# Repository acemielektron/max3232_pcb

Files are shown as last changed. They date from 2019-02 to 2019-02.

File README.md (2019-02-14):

# max3232_pcb
diy single sided pcb for max3232 RS232 to TTL serial

After cheap max3232 pcb was broken i have placed components with the addtion of 3.3k resistors on rs232 inputs on a diy pcb.

Why 3.3k resistors? because these cheap max3232 clones cause crosstalk while connected to a PC RS232 port. 
This was en effective solution. And with the new pcb i added rts and cts.

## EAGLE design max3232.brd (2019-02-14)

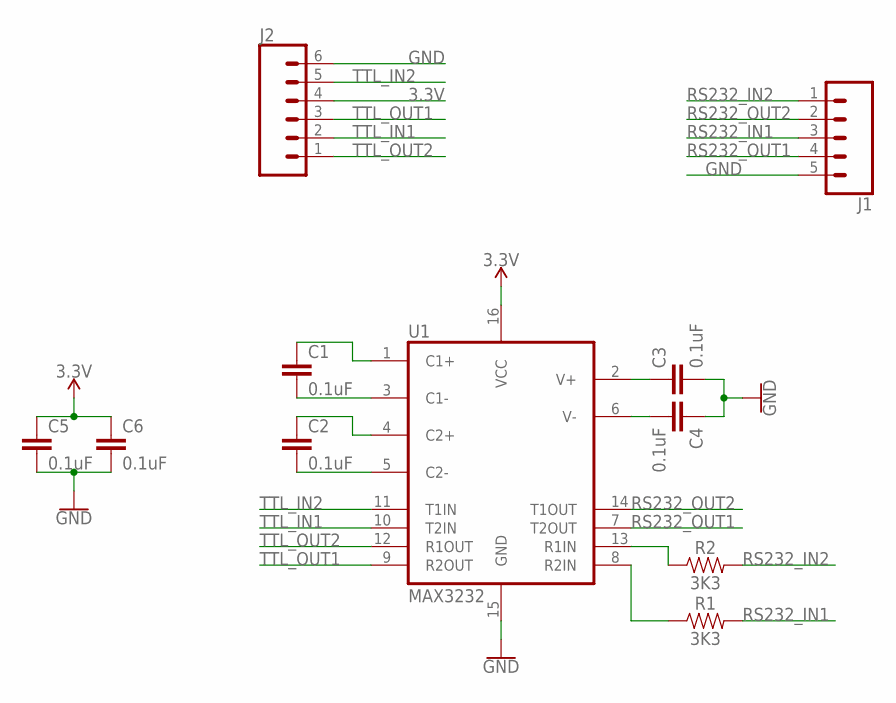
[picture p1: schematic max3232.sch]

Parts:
C1, C2, C3, C4, C5, C6: 0.1uF; 0805
J1: CONN_05; 1X05
J2: CONN_06SILK_FEMALE_PTH; 1X06
R1, R2: 3K3; 1206
U1: MAX3232; SO16

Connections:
3.3V: C5.1, C6.1, J2.4, U1.16 (VCC)
GND: C3.2, C4.1, C5.2, C6.2, J1.5, J2.6, U1.15 (GND)
unnamed: C3.1, U1.2 (V+)
unnamed: C1.2, U1.3 (C1-)
unnamed: C1.1, U1.1 (C1+)
unnamed: C2.2, U1.5 (C2-)
unnamed: C2.1, U1.4 (C2+)
unnamed: C4.2, U1.6 (V-)
unnamed: R2.1, U1.13 (R1IN)
unnamed: R1.1, U1.8 (R2IN)
RS232_IN1: J1.3, R1.2
RS232_IN2: J1.1, R2.2
RS232_OUT1: J1.4, U1.7 (T2OUT)
RS232_OUT2: J1.2, U1.14 (T1OUT)
TTL_IN1: J2.2, U1.10 (T2IN)
TTL_IN2: J2.5, U1.11 (T1IN)
TTL_OUT1: J2.3, U1.9 (R2OUT)
TTL_OUT2: J2.1, U1.12 (R1OUT)

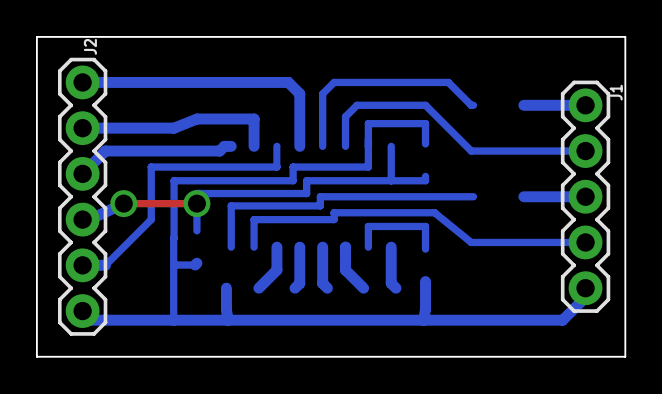
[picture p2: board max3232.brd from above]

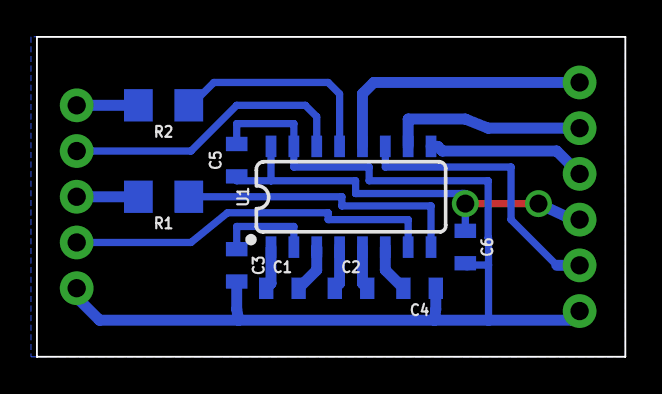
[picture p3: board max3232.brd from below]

Board: 2 copper layers, 32.7 x 17.8 mm, 11 parts (9 on the bottom side), 18 nets.

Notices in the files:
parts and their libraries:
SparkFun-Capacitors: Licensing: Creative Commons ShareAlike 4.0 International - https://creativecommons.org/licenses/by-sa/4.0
